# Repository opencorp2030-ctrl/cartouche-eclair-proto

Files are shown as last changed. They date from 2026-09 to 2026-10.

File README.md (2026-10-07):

# CARTOUCHE Drive



A small USB-C drive for an M.2 2230 NVMe SSD, built around the JMicron JMS583
bridge (USB 3.2 Gen 2, 10 Gb/s → PCIe Gen 3 ×2). It is the prototype drive for
[CARTOUCHE](https://cartouche.candygate.eu), a local AI that runs from a USB drive.

**Status:** schematic v0.1 (ERC 0). PCB v0.4 — 36 × 46 mm, 4 layers (In1 GND, In2 GND + 1.0 V island), 9 high-speed pairs as straight coupled pairs. Impedance from a 2D field solver (`tools/impedance.py`, JLC04161H-7628, with solder mask): USB 3.2 pairs 0.20/0.10 mm ≈ 86 Ω (target 90 Ω ±10 %), PCIe and REFCLK pairs 0.30/0.20 mm ≈ 89 Ω (target 85 Ω ±15 %), GND stitching. DRC: 0 unconnected, 0 schematic mismatch, 2 silkscreen warnings. Fabrication files in `hardware/fab/` (Gerbers zip, JLCPCB BOM and CPL). **Prototype, not verified:** JMS583 must be consigned (0 stock at JLCPCB), CPL rotations to check in the JLCPCB viewer, LED polarity assumed active-low.

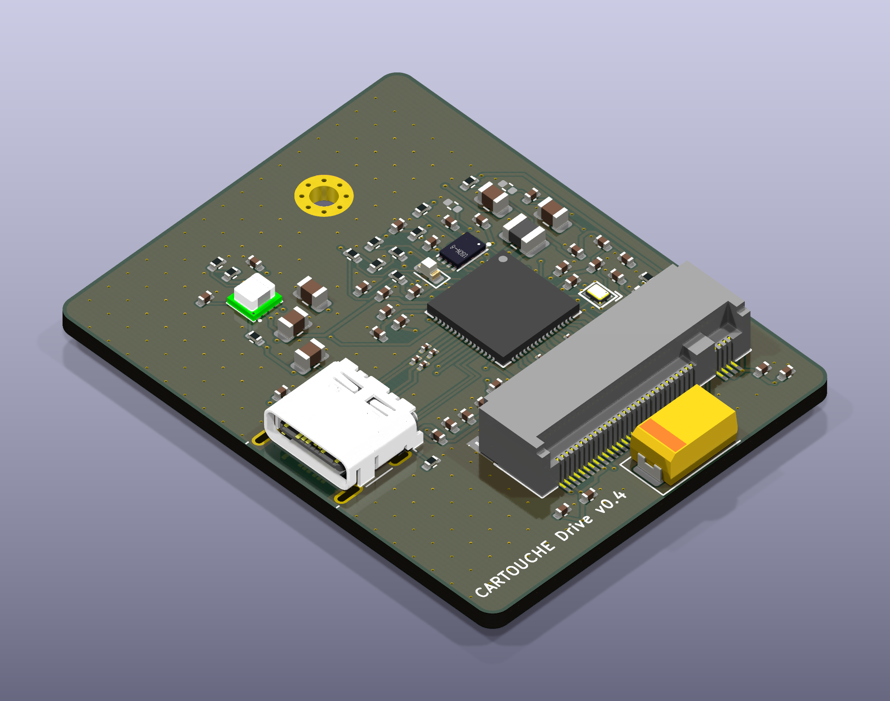
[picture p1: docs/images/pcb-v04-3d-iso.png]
PCB v0.4, 3D view


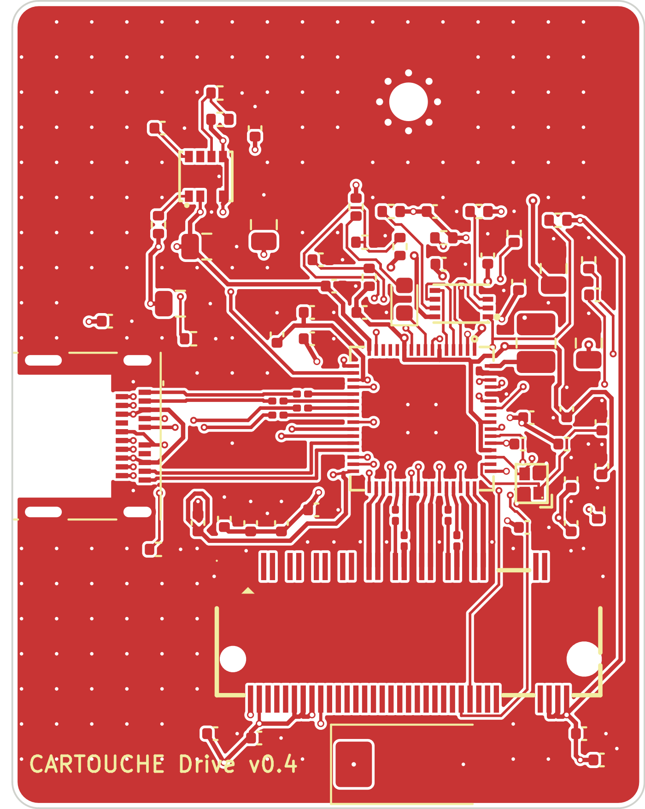
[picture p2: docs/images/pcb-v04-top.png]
top copper
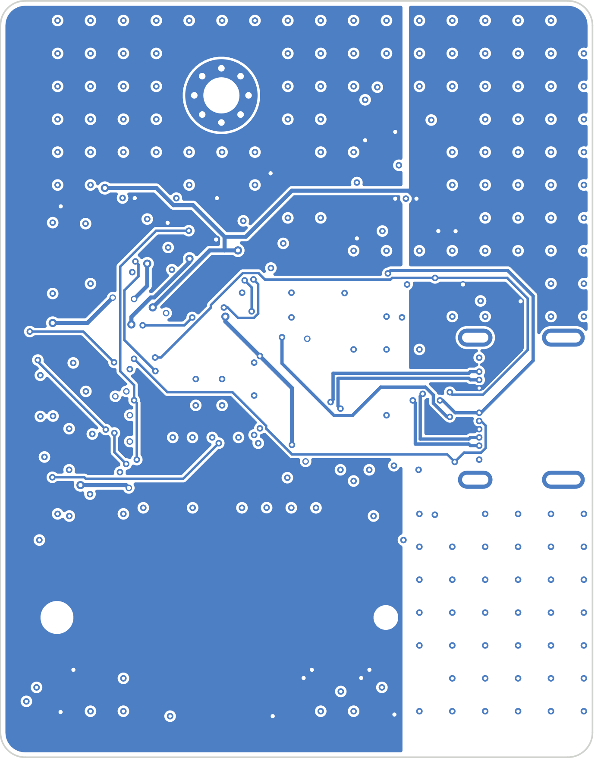
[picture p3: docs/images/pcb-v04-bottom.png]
bottom copper
 

## Blocks

| Block | Parts |
|---|---|
| USB-C (sink, 5 V) | Molex 105450-0101, CC pull-downs 5.1 kΩ, 100 nF on each SuperSpeed TX line |
| Bridge | JMS583 (QFN-64 8×8, 0.4 mm), 25 MHz crystal, REXT 12 kΩ 1 %, reset RC, SPI flash |
| Chip power | JMS583 internal regulators: 5 V → 1.0 V (buck, 4.7 µH) and 5 V → 3.3 V (LDO, chip only) |
| SSD power | TPS82130 3 A buck, 5 V → 3.3 V, 330 µF bulk |
| SSD | LOTES APCI0113 M.2 key M socket, 2 PCIe lanes, 220 nF on each PCIe TX line |

## Files

- `hardware/` — KiCad 9 project (`cartouche-drive.kicad_sch`), local libraries in `hardware/lib/`
- `hardware/cartouche-drive-schematic.pdf` — schematic export
- `tools/gen_schematic.py` — the connection list that generates the schematic
- `tools/build_pcb.py` — board, placement, planes and fan-out vias (KiCad Python)
- `tools/route_pcb.py` — net classes and Freerouting run

## References

- JMS583 datasheet PDS-17001 rev 1.0 (JMicron) — pin-out and required parts
- Part footprints: LCSC / EasyEDA libraries (LOTES C841669, Molex C134092, TPS82130 C473914)

## Sponsors

Thank you to the companies that support this open-source board:

<a href="https://aisler.net">AISLER</a>

- **[AISLER](https://aisler.net) is the PCB sponsor of this project** (boards, stencils and shipping, made in Europe). The AISLER logo is printed on the back of the board (placeholder on `B.Silkscreen`, `tools/aisler_logo.py`). Order your own with the button above.
- **[JMicron](https://www.jmicron.com)**, through its distributor **[BONMECK](https://www.bonmeck.com)**, provides free JMS583 bridge chip samples for the first prototypes.

Results of the prototypes, good or bad, will be published here.

## License

Open source. Hardware (`hardware/`, `docs/`): [CERN-OHL-S-2.0](LICENSE-HARDWARE). Tools (`tools/`): MIT.
See [LICENSE](LICENSE). Third-party libraries used in the KiCad project (KiCad standard libraries, LCSC/EasyEDA
footprints and 3D models) stay under their own licenses.

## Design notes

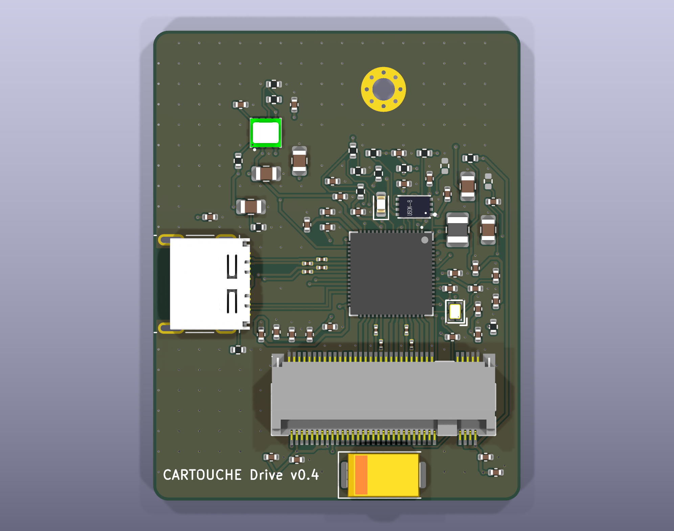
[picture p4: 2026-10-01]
docs/images/pcb-v04-3d-top.png

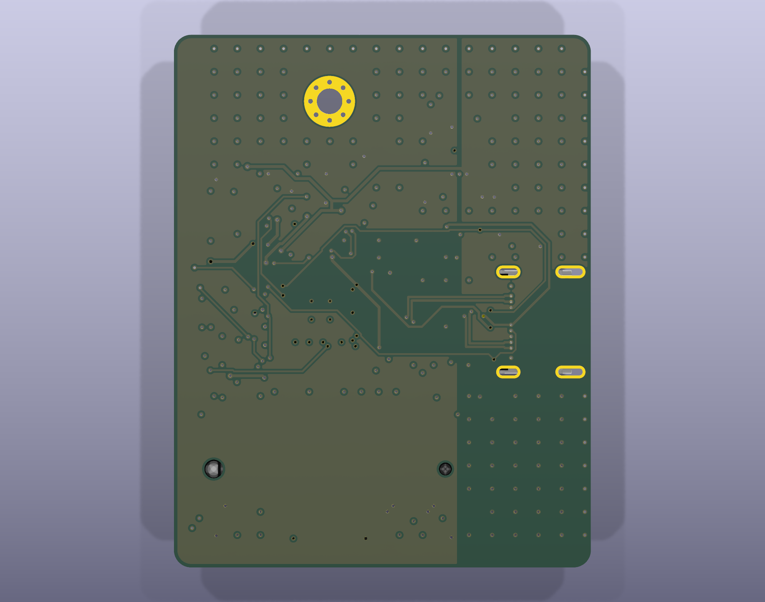
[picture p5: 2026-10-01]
docs/images/pcb-v04-3d-bottom.png

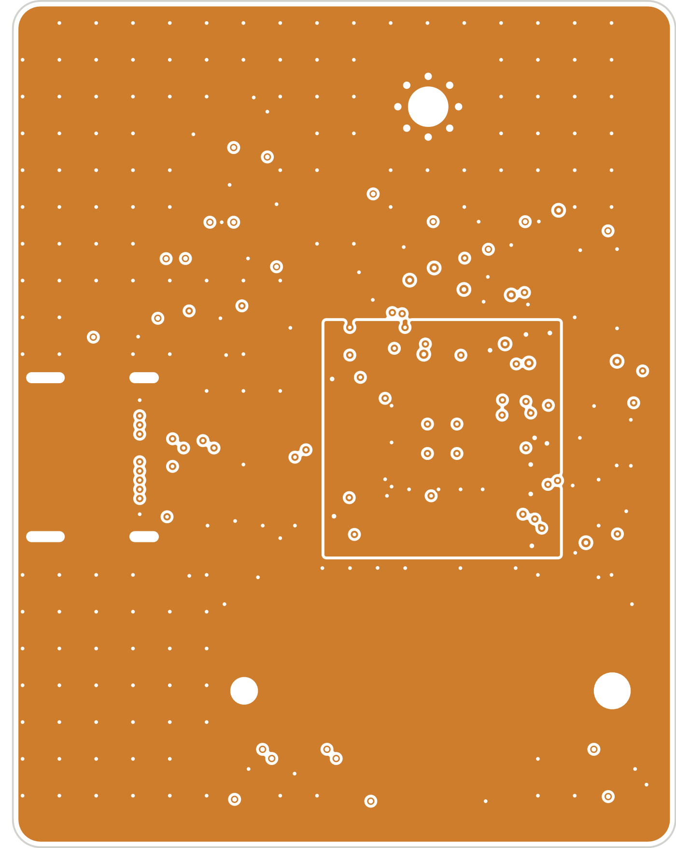
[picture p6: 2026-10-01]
docs/images/pcb-v04-in2.png

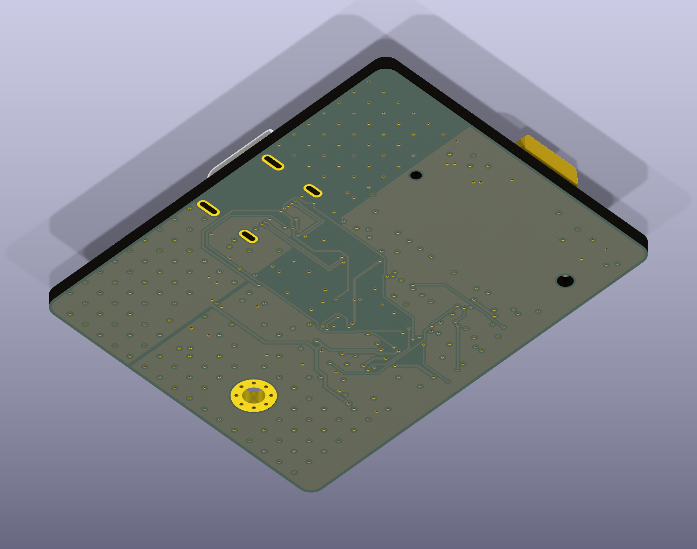
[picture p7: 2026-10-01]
docs/images/pcb-v04-3d-iso-bottom.png

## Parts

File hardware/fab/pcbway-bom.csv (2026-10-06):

Item | Designator | Qty | Manufacturer | Mfg Part # | Description / Value | Package/Footprint | LCSC Part # | Type
1 | C1,C2,C3,C4 | 4 | muRata | GRM033R61A104KE15D | 100nF ±10% 10V Ceramic Capacitor X5R 0201 | 0201 | C76934 | SMD
2 | C5,C28,C38 | 3 | Samsung Electro-Mechanics | CL21A106KAYNNNE | 10uF ±10% 25V Ceramic Capacitor X5R 0805 | 0805 | C15850 | SMD
3 | C6,C9,C10,C11,C12,C13,C14,C15,C16,C17,C18,C19,C20,C23,C24,C25,C26,C27,C29,C33,C42 | 21 | Samsung Electro-Mechanics | CL05B104KO5NNNC | 100nF ±10% 16V Ceramic Capacitor X7R 0402 | 0402 | C1525 | SMD
4 | C7,C40 | 2 | Samsung Electro-Mechanics | CL21A226MAQNNNE | 22uF ±20% 25V Ceramic Capacitor X5R 0805 | 0805 | C45783 | SMD
5 | C8,C22,C43,C44,C45,C46 | 6 | Samsung Electro-Mechanics | CL05A106MQ5NUNC | 10uF ±20% 6.3V Ceramic Capacitor X5R 0402 | 0402 | C15525 | SMD
6 | C21,C30 | 2 | Samsung Electro-Mechanics | CL05A105KA5NQNC | 1uF ±10% 25V Ceramic Capacitor X5R 0402 | 0402 | C52923 | SMD
7 | C31,C32 | 2 | FH | 0402CG180J500NT | 18pF ±5% 50V Ceramic Capacitor C0G 0402 | 0402 | C1549 | SMD
8 | C34,C35,C36,C37 | 4 | muRata | GRM033R60J224ME15D | 220nF ±20% 6.3V Ceramic Capacitor X5R 0201 | 0201 | C76932 | SMD
9 | C39 | 1 | FH | 0402B332K500NT | 3.3nF ±10% 50V Ceramic Capacitor X7R 0402 | 0402 | C1536 | SMD
10 | C41 | 1 | Kyocera AVX | TAJD337M010RNJ | 330uF ±20% 10V Tantalum Capacitors 900mΩ@100kHz CASE-D-7343 | CASE-D-7343-31(mm) | C105408 | SMD
11 | J1 | 1 | MOLEX | 1054500101 | USB-C (USB TYPE-C) Receptacle Connector 24 Position Surface Mount | SMD | C134092 | SMD
12 | J2 | 1 | LOTES | APCI0113-P001A | 67P Surface Mount, Right Angle SMD,P=0.5mm,Surface Mount,Right Angle Centronics Connectors | SMD,P=0.5mm,Surface Mount,Right Angle | C841669 | SMD
13 | L1 | 1 | TDK | MLP2520S4R7ST0S1 | 1A 4.7uH ±20% 110mΩ Multilayer inductor 1008 Fixed Inductors RoHS | 1008 | C383386 | SMD
14 | LED1 | 1 | Hubei KENTO Elec | KT-0603R | Red 645nm LED Indication - Discrete 2.4V 0603 | 0603 | C2286 | SMD
15 | R1,R2 | 2 | UNI-ROYAL | 0402WGF5101TCE | 5.1kΩ ±1% 62.5mW 0402 Thick Film Resistor | 0402 | C25905 | SMD
16 | R3,R6,R10,R11,R12,R13,R14 | 7 | UNI-ROYAL | 0402WGF1002TCE | 10kΩ ±1% 62.5mW 0402 Thick Film Resistor | 0402 | C25744 | SMD
17 | R4 | 1 | UNI-ROYAL | 0402WGF2002TCE | 20kΩ ±1% 62.5mW 0402 Thick Film Resistor | 0402 | C25765 | SMD
18 | R5 | 1 | UNI-ROYAL | 0402WGF1202TCE | 12kΩ ±1% 62.5mW 0402 Thick Film Resistor | 0402 | C25752 | SMD
19 | R9 | 1 | UNI-ROYAL | 0402WGF1001TCE | 1kΩ ±1% 62.5mW 0402 Thick Film Resistor | 0402 | C11702 | SMD
20 | R15 | 1 | FOJAN | FRC0402F4753TS | 475kΩ ±1% 62.5mW 0402 Thick Film Resistor | 0402 | C5713272 | SMD
21 | R16 | 1 | FOJAN | FRC0402F1503TS | 150kΩ ±1% 62.5mW 0402 Thick Film Resistor | 0402 | C2909320 | SMD
22 | U1 | 1 | JMicron | JMS583 | USB 3.2 Gen 2 to PCIe Gen 3 x2 NVMe bridge (needs SPI flash firmware). Please quote sourcing; customer can supply if not available | QFN-64 (8x8 mm) | C9900110183 | SMD
23 | U2 | 1 | TI | TPS82130SILR | Step-down type 900mV~6V 3V~17V USIP-8 DC DC Converters RoHS | USIP-8 | C473914 | SMD
24 | U3 | 1 | Zetta | ZD25WQ16CEIGR | 16Mbit 1.65V~3.6V 104MHz SPI USON-8(2x3) Memory RoHS | USON-8(2x3) | C7304007 | SMD
25 | Y1 | 1 | SCTF | SX0B25.000F1210F30 | Crystal 25MHz ±10ppm 12pF 200Ω SMD1612-4P | SMD1612-4P | C7301914 | SMD

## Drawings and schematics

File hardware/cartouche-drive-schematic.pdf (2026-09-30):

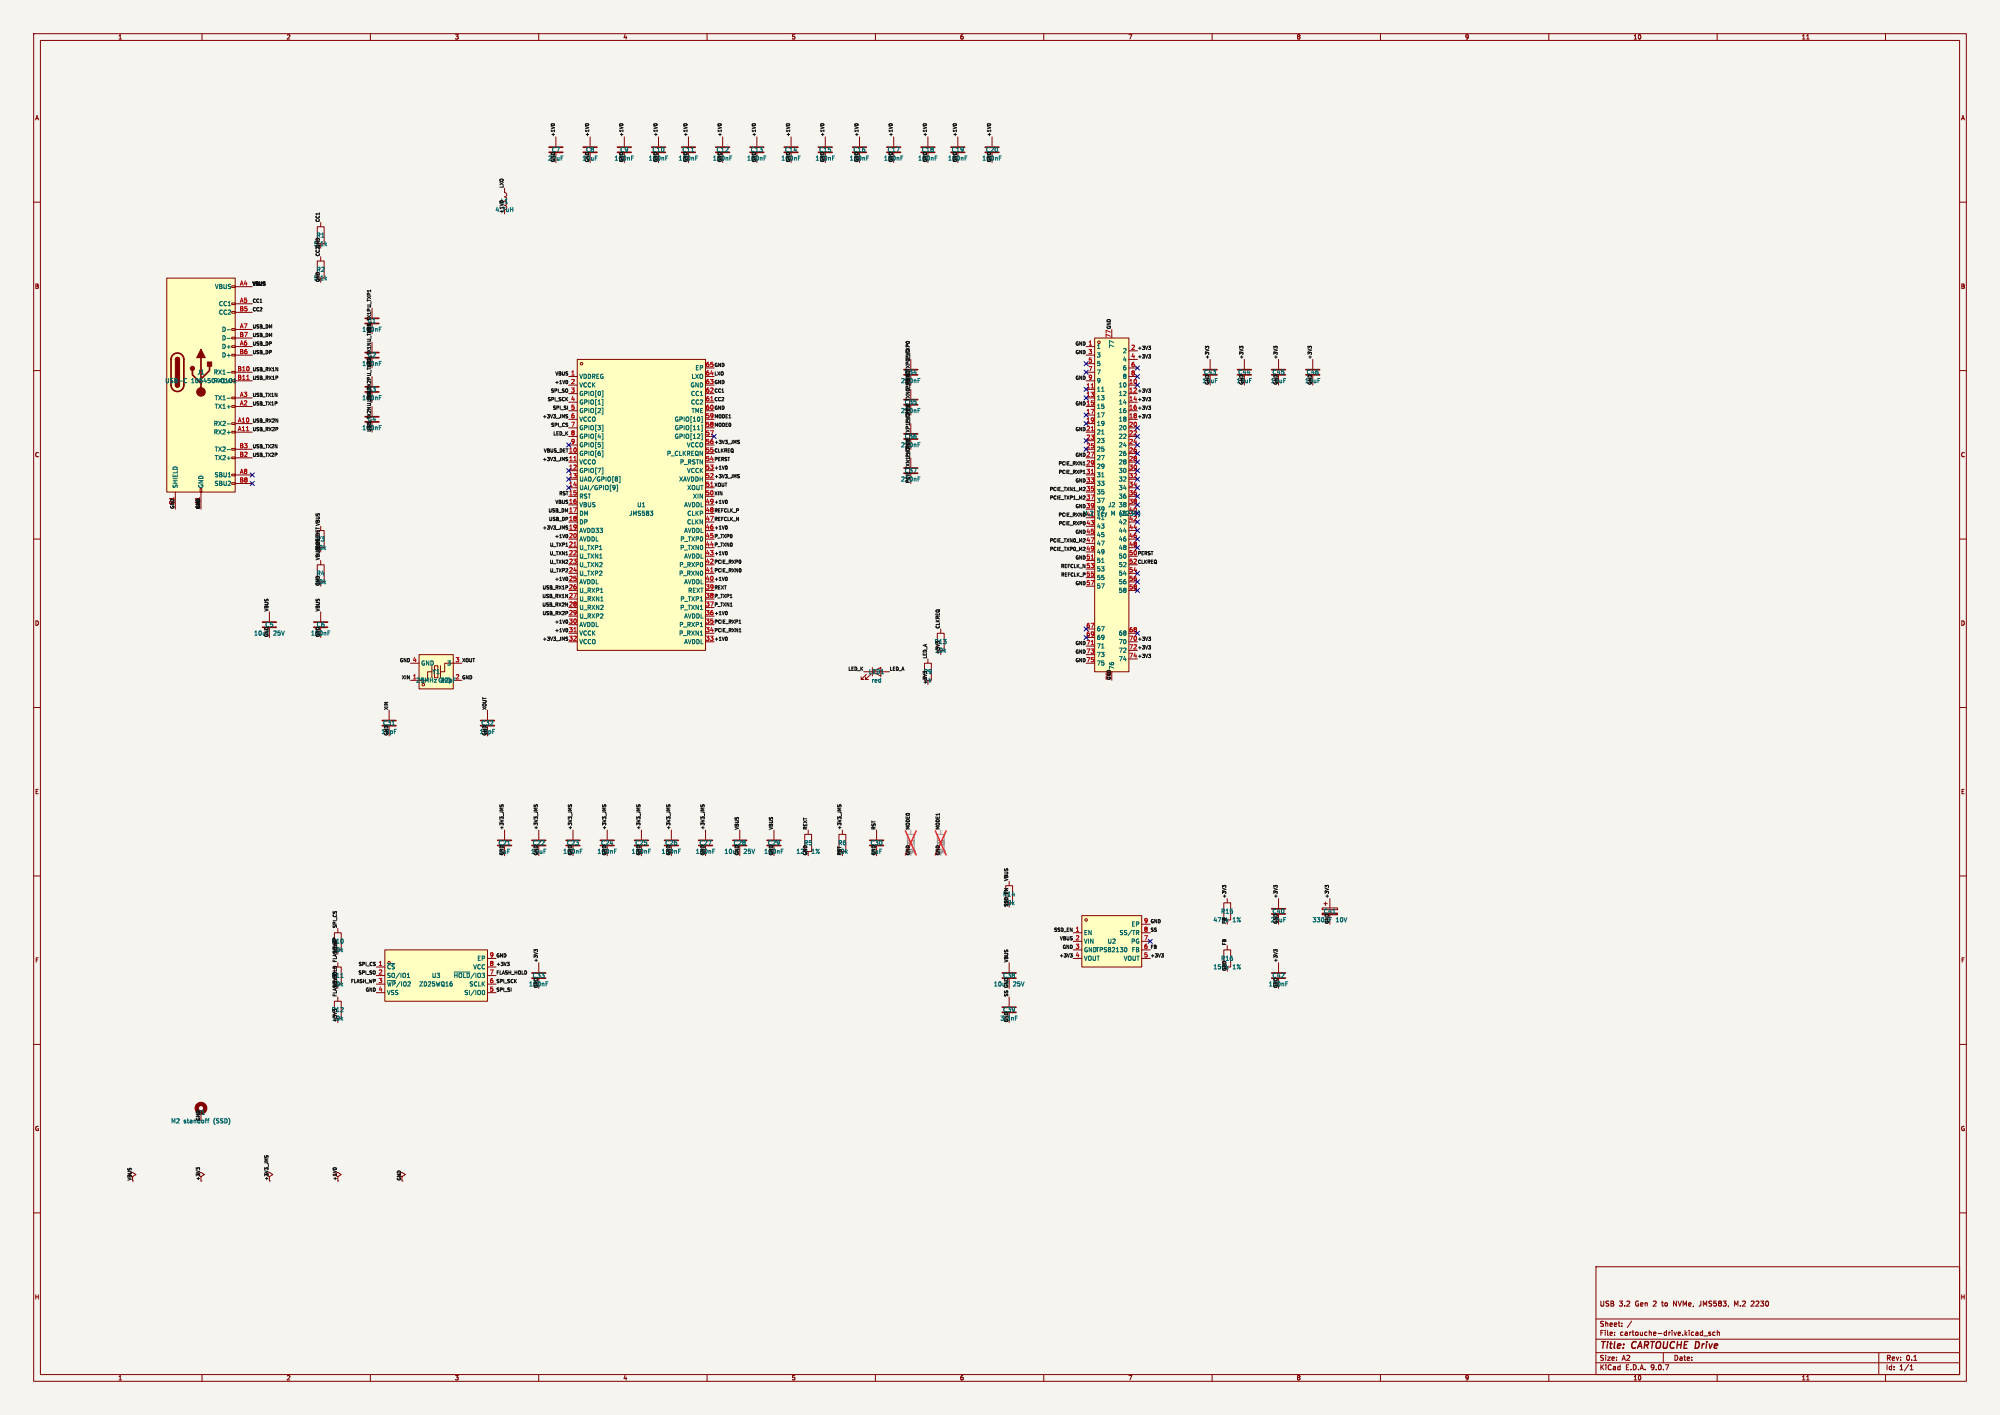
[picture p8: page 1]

LXO 64 GND 63 CC1 62 CC2 61 TME 60 GPIO[10] 59 GPIO[11] 58 GPIO[12] 57 VCCO 56 P_CLKREQN 55 P_RSTN 54 VCCK 53 XAVDDH 52 XOUT 51 XIN 50 AVDDL 49 CLKP 48 CLKN 47 AVDDL 46 P_TXP0 45 P_TXN0 44 AVDDL 43 P_RXP0 42 P_RXN0 41 AVDDL 40 REXT 39 P_TXP1 38 P_TXN1 37 AVDDL 36 P_RXP1 35 P_RXN1 34 AVDDL 33 U1

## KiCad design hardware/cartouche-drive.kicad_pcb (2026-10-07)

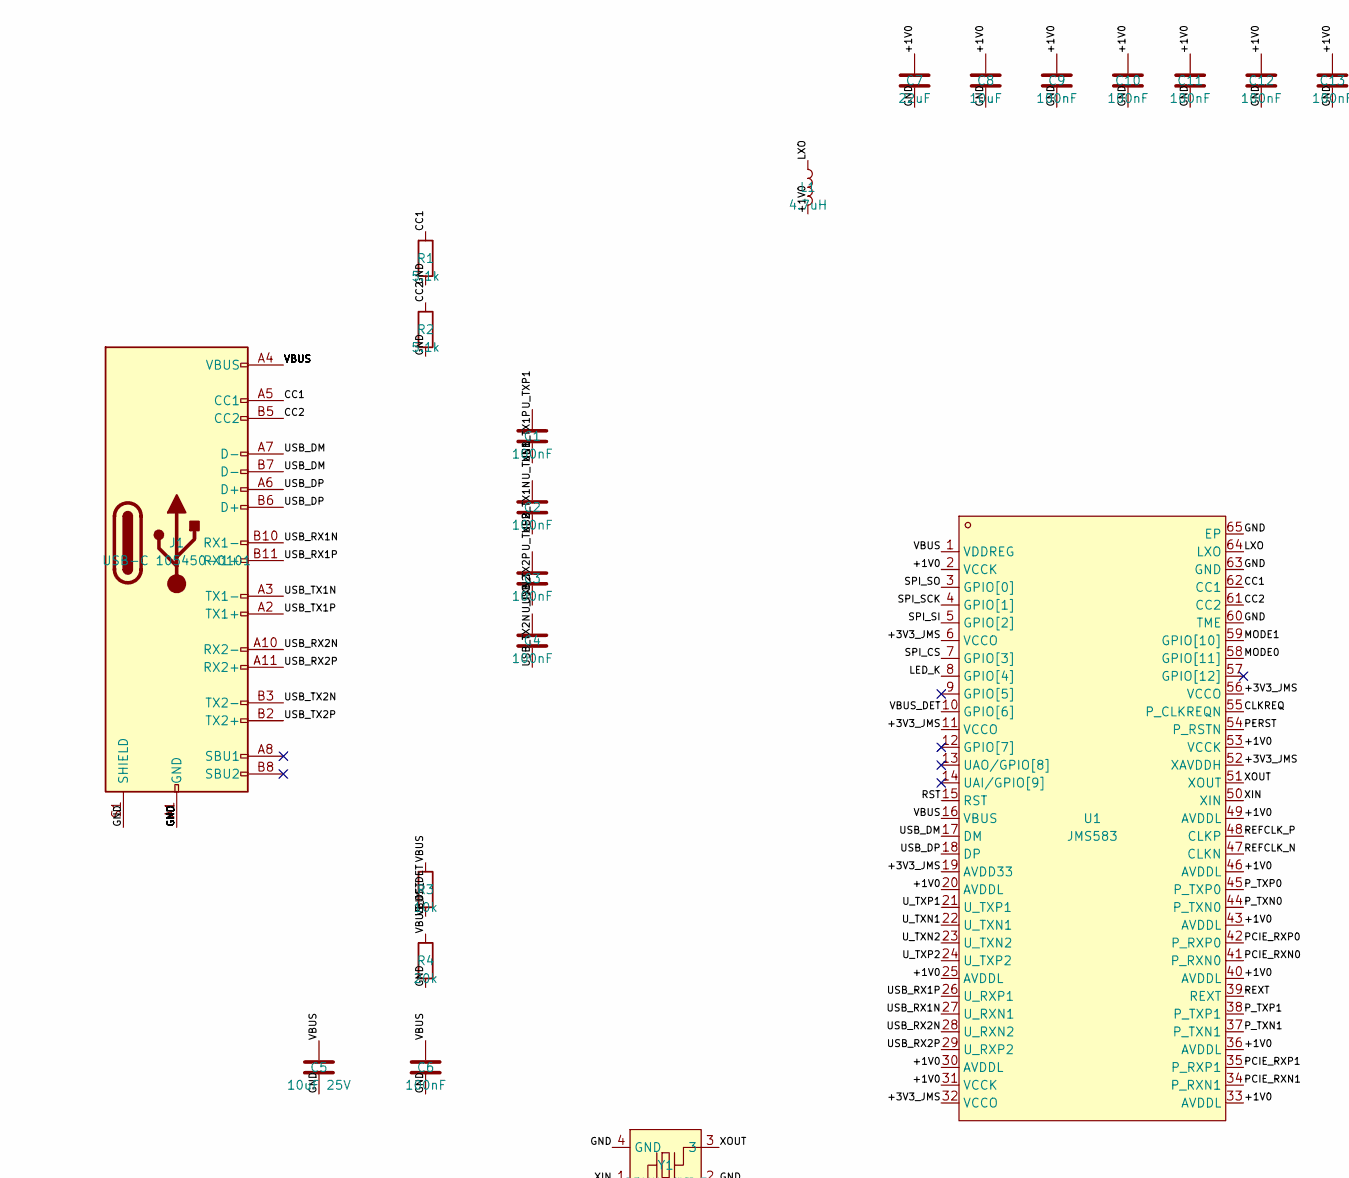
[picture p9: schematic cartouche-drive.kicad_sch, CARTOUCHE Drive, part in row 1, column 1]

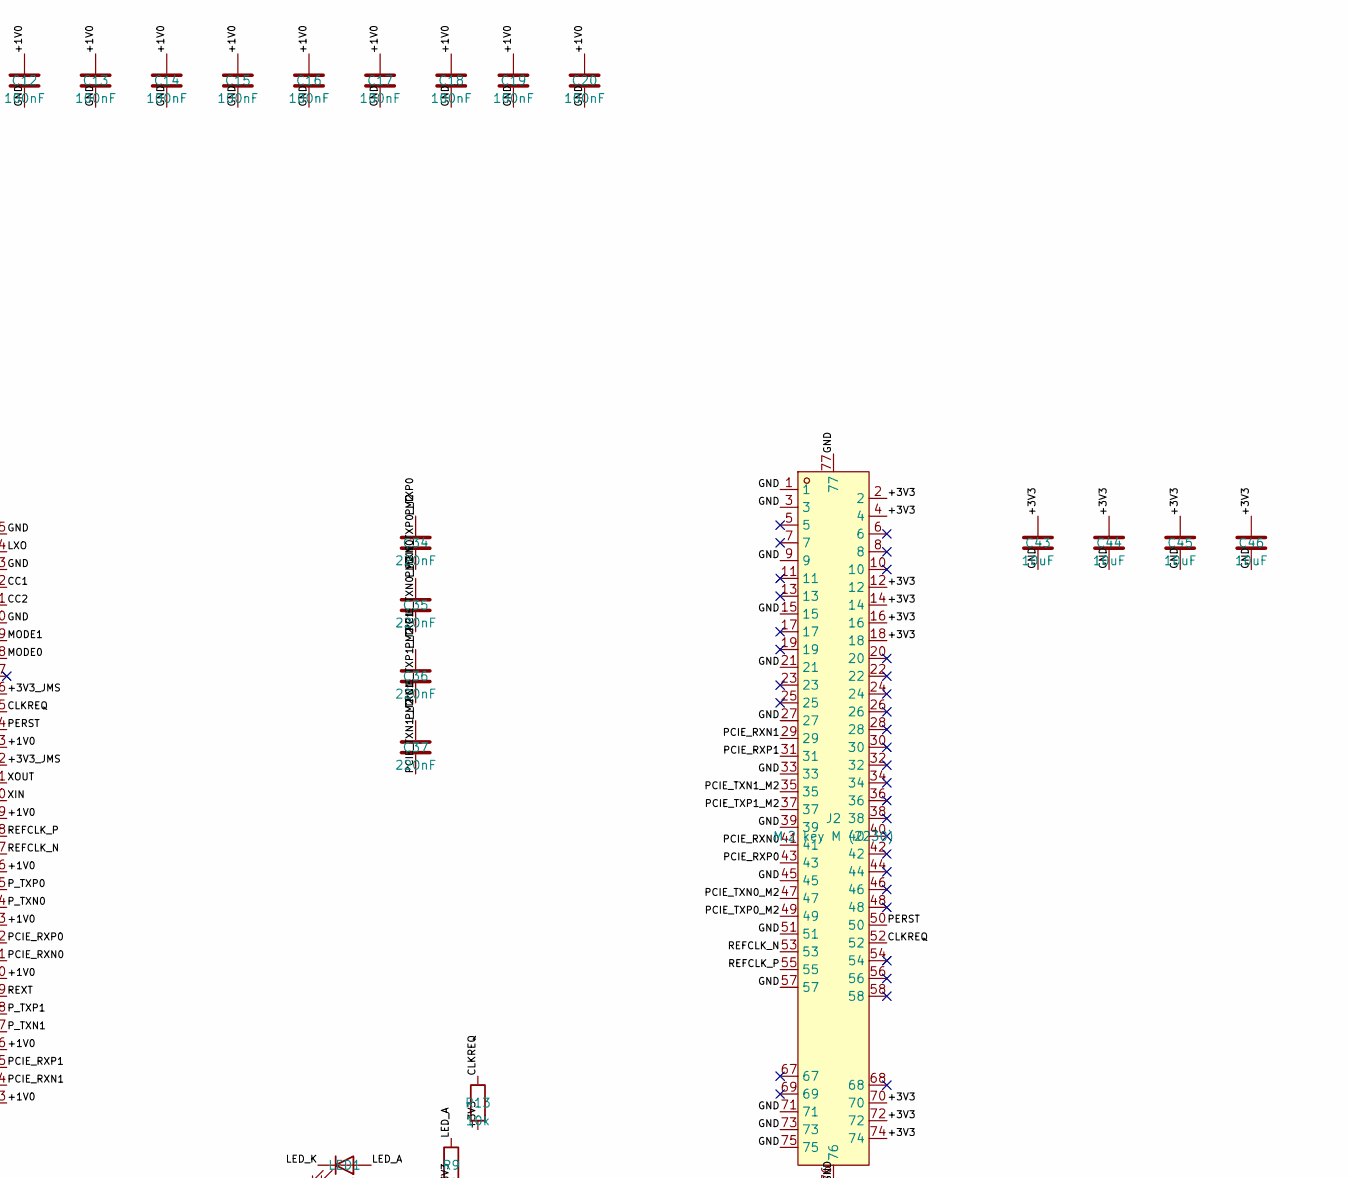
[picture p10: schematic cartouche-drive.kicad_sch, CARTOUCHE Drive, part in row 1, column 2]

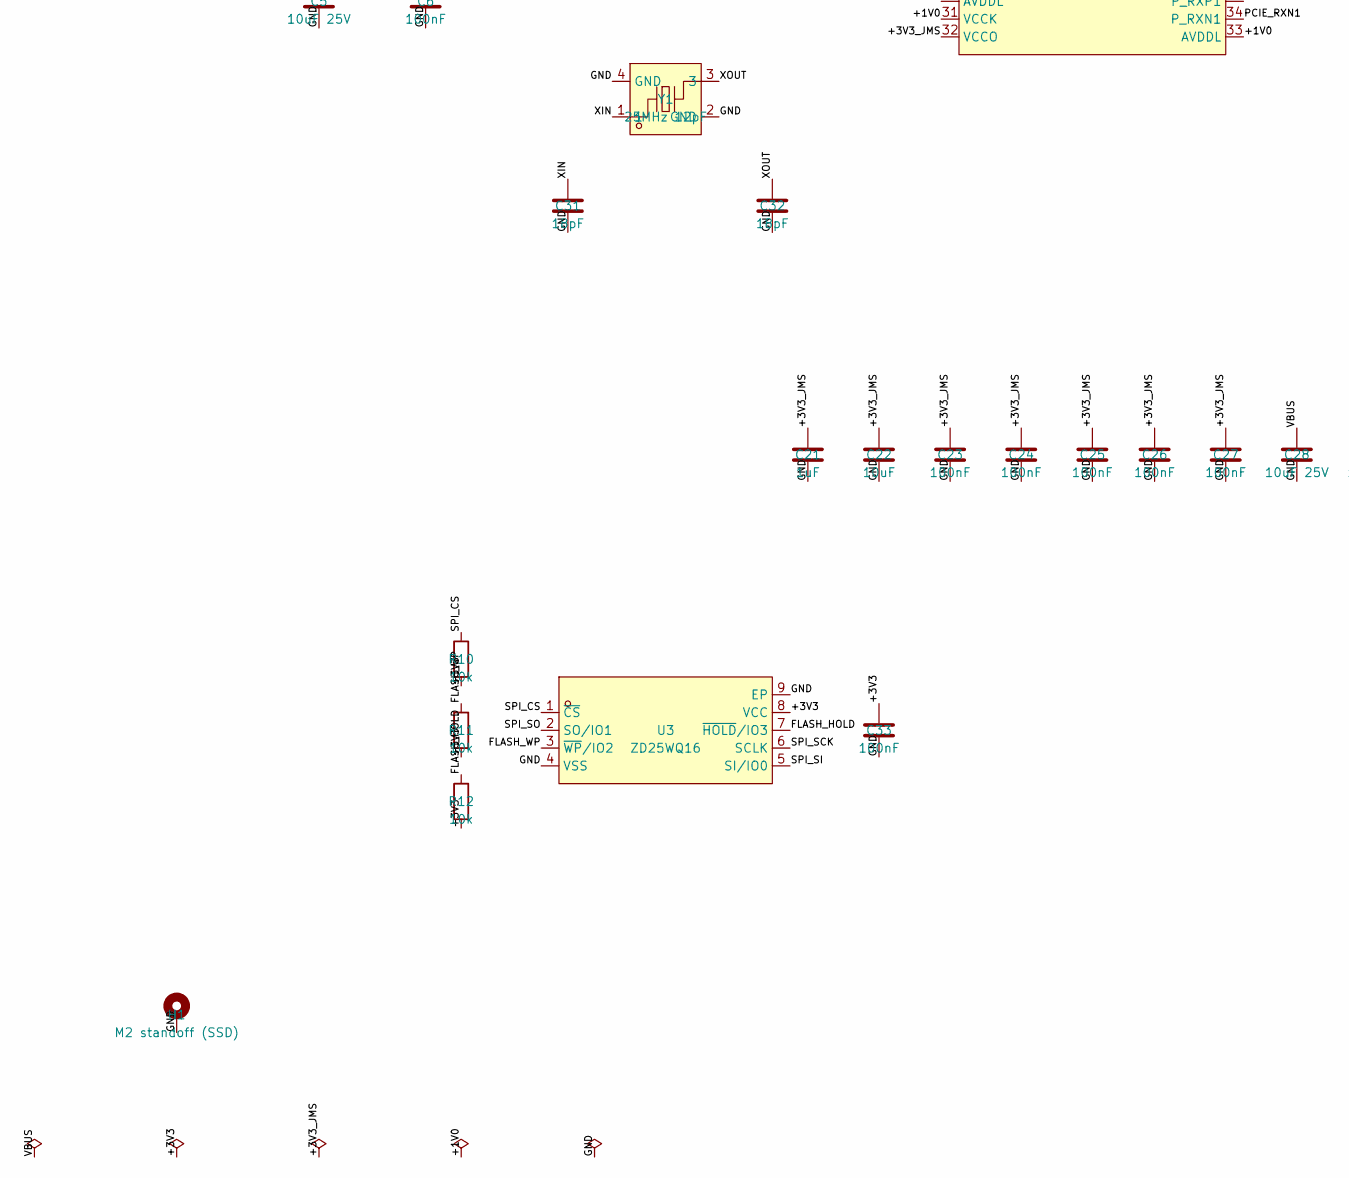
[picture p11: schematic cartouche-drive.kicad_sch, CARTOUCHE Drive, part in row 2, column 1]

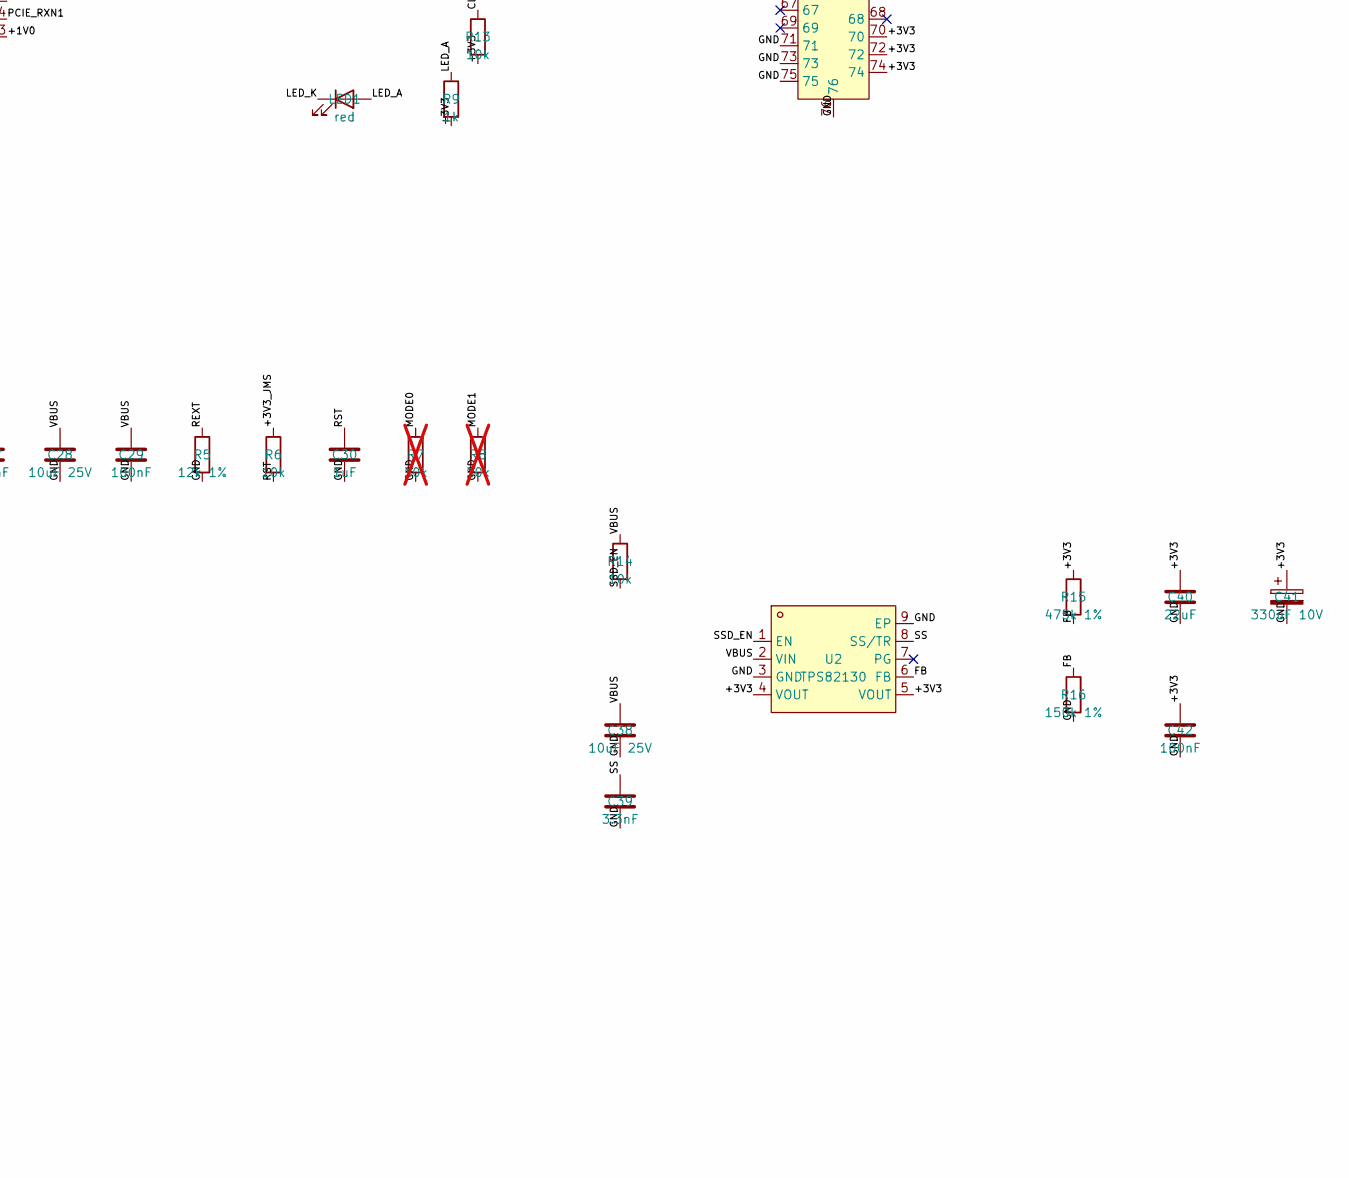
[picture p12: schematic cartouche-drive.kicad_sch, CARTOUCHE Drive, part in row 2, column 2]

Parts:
C1, C2, C3, C4: 100nF; C_0201_0603Metric; LCSC C76934
C5, C28, C38: 10uF 25V; C_0805_2012Metric; LCSC C15850
C6, C9, C10, C11, C12, C13, C14, C15, C16, C17, C18, C19, C20, C23, C24, C25, C26, C27, C29, C33, C42: 100nF; C_0402_1005Metric; LCSC C1525
C7, C40: 22uF; C_0805_2012Metric; LCSC C45783
C8, C22, C43, C44, C45, C46: 10uF; C_0402_1005Metric; LCSC C15525
C21, C30: 1uF; C_0402_1005Metric; LCSC C52923
C31, C32: 18pF; C_0402_1005Metric; LCSC C1549
C34, C35, C36, C37: 220nF; C_0201_0603Metric; LCSC C76932
C39: 3.3nF; C_0402_1005Metric; LCSC C1536
C41: 330uF 10V; CP_EIA-7343-31_Kemet-D; LCSC C105408
H1: M2 standoff (SSD); MountingHole_2.2mm_M2_Pad_Via
J1: USB-C 105450-0101; USB_C_Receptacle_Molex_105450-0101; LCSC C134092
J2: M.2 key M (2230); CONN-SMD_APCI0113-P001A; LCSC C841669
L1: 4.7uH; L_1008_2520Metric; LCSC C383386
LED1: red; LED_0603_1608Metric; LCSC C2286
R1, R2: 5.1k; R_0402_1005Metric; LCSC C25905
R3, R6, R10, R11, R12, R13, R14: 10k; R_0402_1005Metric; LCSC C25744
R4: 20k; R_0402_1005Metric; LCSC C25765
R5: 12k 1%; R_0402_1005Metric; LCSC C25752
R7, R8: 10k; R_0402_1005Metric; LCSC C25744; not fitted
R9: 1k; R_0402_1005Metric; LCSC C11702
R15: 475k 1%; R_0402_1005Metric; LCSC C5713272
R16: 150k 1%; R_0402_1005Metric; LCSC C2909320
U1: JMS583; QFN-64_L8.0-W8.0-P0.40-TL-EP4.5; LCSC C9900110183
U2: TPS82130; USIP-8_L3.0-W2.8-P0.65-TL-EP; LCSC C473914
U3: ZD25WQ16; USON-8_L3.0-W2.0-P0.50-BL-EP; LCSC C7304007
Y1: 25MHz 12pF; CRYSTAL-SMD_4P-L1.6-W1.2-BL; LCSC C7301914

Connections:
/+1V0: C7.1, C8.1, C9.1, C10.1, C11.1, C12.1, C13.1, C14.1, C15.1, C16.1, C17.1, C18.1, C19.1, C20.1, L1.2, U1.2 (VCCK), U1.20 (AVDDL), U1.25 (AVDDL), U1.30 (AVDDL), U1.31 (VCCK), U1.33 (AVDDL), U1.36 (AVDDL), U1.40 (AVDDL), U1.43 (AVDDL), U1.46 (AVDDL), U1.49 (AVDDL), U1.53 (VCCK)
/+3V3: C33.1, C40.1, C41.1, C42.1, C43.1, C44.1, C45.1, C46.1, J2.2, J2.4, J2.12, J2.14, J2.16, J2.18, J2.70, J2.72, J2.74, R9.2, R10.2, R11.2, R12.2, R13.2, R15.1, U2.4 (VOUT), U2.5 (VOUT), U3.8 (VCC)
/+3V3_JMS: C21.1, C22.1, C23.1, C24.1, C25.1, C26.1, C27.1, R6.1, U1.6 (VCCO), U1.11 (VCCO), U1.19 (AVDD33), U1.32 (VCCO), U1.52 (XAVDDH), U1.56 (VCCO)
/CC1: J1.A5 (CC1), R1.1, U1.62 (CC1)
/CC2: J1.B5 (CC2), R2.1, U1.61 (CC2)
/CLKREQ: J2.52, R13.1, U1.55 (P_CLKREQN)
/FB: R15.2, R16.1, U2.6 (FB)
/FLASH_HOLD: R12.1, U3.7 (~HOLD/IO3)
/FLASH_WP: R11.1, U3.3 (~WP/IO2)
/GND: C5.2, C6.2, C7.2, C8.2, C9.2, C10.2, C11.2, C12.2, C13.2, C14.2, C15.2, C16.2, C17.2, C18.2, C19.2, C20.2, C21.2, C22.2, C23.2, C24.2, C25.2, C26.2, C27.2, C28.2, C29.2, C30.2, C31.2, C32.2, C33.2, C38.2, C39.2, C40.2, C41.2, C42.2, C43.2, C44.2, C45.2, C46.2, H1.1, J1.A1 (GND), J1.A12 (GND), J1.B1 (GND), J1.B12 (GND), J1.S1 (SHIELD), J2.1, J2.3, J2.9, J2.15, J2.21, J2.27, J2.33, J2.39, J2.45, J2.51, J2.57, J2.71, J2.73, J2.75, J2.76, J2.77, R1.2, R2.2, R4.2, R5.2, R7.2, R8.2, R16.2, U1.60 (TME), U1.63 (GND), U1.65 (EP), U2.3 (GND), U2.9 (EP), U3.4 (VSS), U3.9 (EP), Y1.2 (GND), Y1.4 (GND)
/LED_A: LED1.2 (A), R9.1
/LED_K: LED1.1 (K), U1.8 (GPIO[4])
/LXO: L1.1, U1.64 (LXO)
/MODE0: R7.1, U1.58 (GPIO[11])
/MODE1: R8.1, U1.59 (GPIO[10])
/PCIE_RXN0: J2.41, U1.41 (P_RXN0)
/PCIE_RXN1: J2.29, U1.34 (P_RXN1)
/PCIE_RXP0: J2.43, U1.42 (P_RXP0)
/PCIE_RXP1: J2.31, U1.35 (P_RXP1)
/PCIE_TXN0_M2: C35.2, J2.47
/PCIE_TXN1_M2: C37.2, J2.35
/PCIE_TXP0_M2: C34.2, J2.49
/PCIE_TXP1_M2: C36.2, J2.37
/PERST: J2.50, U1.54 (P_RSTN)
/P_TXN0: C35.1, U1.44 (P_TXN0)
/P_TXN1: C37.1, U1.37 (P_TXN1)
/P_TXP0: C34.1, U1.45 (P_TXP0)
/P_TXP1: C36.1, U1.38 (P_TXP1)
/REFCLK_N: J2.53, U1.47 (CLKN)
/REFCLK_P: J2.55, U1.48 (CLKP)
/REXT: R5.1, U1.39 (REXT)
/RST: C30.1, R6.2, U1.15 (RST)
/SPI_CS: R10.1, U1.7 (GPIO[3]), U3.1 (~CS)
/SPI_SCK: U1.4 (GPIO[1]), U3.6 (SCLK)
/SPI_SI: U1.5 (GPIO[2]), U3.5 (SI/IO0)
/SPI_SO: U1.3 (GPIO[0]), U3.2 (SO/IO1)
/SS: C39.1, U2.8 (SS/TR)
/SSD_EN: R14.2, U2.1 (EN)
/USB_DM: J1.A7 (D-), J1.B7 (D-), U1.17 (DM)
/USB_DP: J1.A6 (D+), J1.B6 (D+), U1.18 (DP)
/USB_RX1N: J1.B10 (RX1-), U1.27 (U_RXN1)
/USB_RX1P: J1.B11 (RX1+), U1.26 (U_RXP1)
/USB_RX2N: J1.A10 (RX2-), U1.28 (U_RXN2)
/USB_RX2P: J1.A11 (RX2+), U1.29 (U_RXP2)
/USB_TX1N: C2.2, J1.A3 (TX1-)
/USB_TX1P: C1.2, J1.A2 (TX1+)
/USB_TX2N: C4.2, J1.B3 (TX2-)
/USB_TX2P: C3.2, J1.B2 (TX2+)
/U_TXN1: C2.1, U1.22 (U_TXN1)
/U_TXN2: C4.1, U1.23 (U_TXN2)
/U_TXP1: C1.1, U1.21 (U_TXP1)
/U_TXP2: C3.1, U1.24 (U_TXP2)
/VBUS: C5.1, C6.1, C28.1, C29.1, C38.1, J1.A4 (VBUS), J1.A9 (VBUS), J1.B4 (VBUS), J1.B9 (VBUS), R3.1, R14.1, U1.1 (VDDREG), U1.16 (VBUS), U2.2 (VIN)
/VBUS_DET: R3.2, R4.1, U1.10 (GPIO[6])
/XIN: C31.1, U1.50 (XIN), Y1.1
/XOUT: C32.1, U1.51 (XOUT), Y1.3

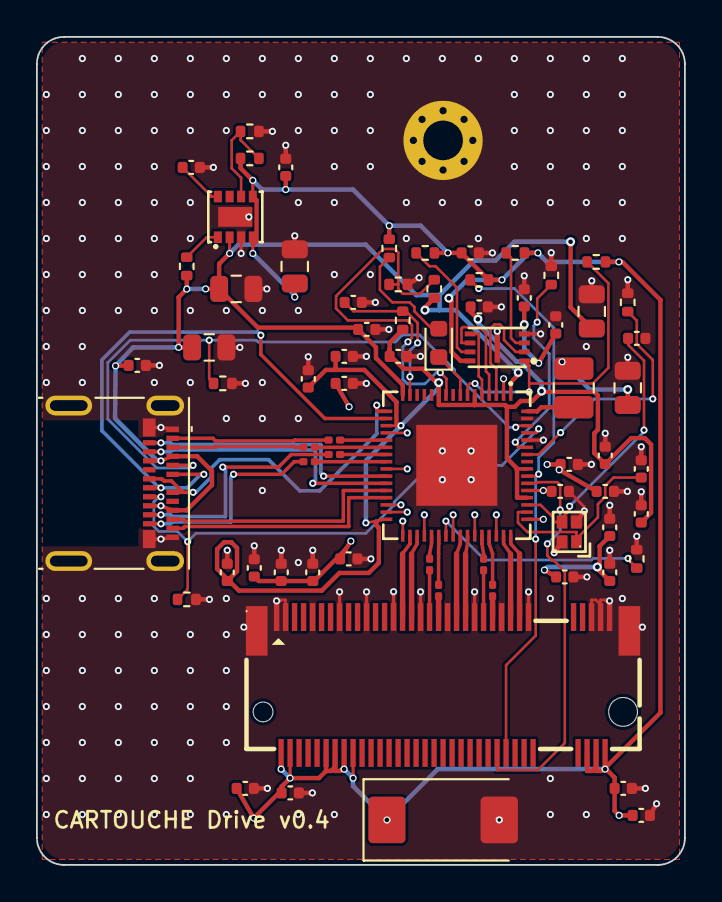
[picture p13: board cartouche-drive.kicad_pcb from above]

Board: 4 copper layers, 36.0 x 46.0 mm, 71 parts (0 on the bottom side), 56 nets.

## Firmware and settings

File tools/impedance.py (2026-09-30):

"""2D field solver for the board's outer-layer lines (finite differences, Laplace).

  python3 tools/impedance.py        (needs numpy and scipy)

Stack-up JLC04161H-7628 (JLCPCB 4 layers, 1.6 mm): L1 copper 0.035 mm over 0.2104 mm
of 7628 prepreg (er 4.4) above the L2 ground plane. Solder mask 0.015 mm, er 3.8.
Prints single-ended and differential (edge-coupled) impedances; the differential one
is twice the odd-mode impedance, computed as 1 / (c * sqrt(C * C_air)).
"""
import numpy as np
import scipy.sparse as sp
import scipy.sparse.linalg as spl

D = 0.005                        # grid step, mm
H, T, ER = 0.2104, 0.035, 4.4    # prepreg, copper, prepreg permittivity
TM, ERM = 0.015, 3.8             # solder mask
C0 = 299792458.0
E0 = 8.8541878128e-12


def solve(w, s=None, mask=True, air=False):
    nx, ny = int(round(4.0 / D)), int(round(1.5 / D))
    jh, jt = int(round(H / D)), int(round((H + T) / D))
    xc = nx // 2
    wi = int(round(w / D))
    if s is None:
        spans = [(xc - wi // 2, xc - wi // 2 + wi, 1.0)]
    else:
        si = int(round(s / D))
        a = xc - si // 2
        spans = [(a - wi, a, 1.0), (a + si, a + si + wi, -1.0)]
    # cell permittivity (cells between nodes), rows 0..ny-1, cols 0..nx-1
    eps = np.ones((ny, nx))
    if not air:
        eps[:jh, :] = ER
        if mask:
            m = int(round(TM / D))
            eps[jh:jh + m, :] = ERM
            for x0, x1, _ in spans:
                eps[jh:jt + m, max(x0 - m, 0):x1 + m] = ERM
    # node potentials fixed: plane row 0 and outer box = 0, traces = ±1
    fixed = np.zeros((ny + 1, nx + 1), bool)
    val = np.zeros((ny + 1, nx + 1))
    fixed[0, :] = fixed[-1, :] = True
    fixed[:, 0] = fixed[:, -1] = True
    for x0, x1, v in spans:
        fixed[jh:jt + 1, x0:x1 + 1] = True
        val[jh:jt + 1, x0:x1 + 1] = v
    idx = -np.ones(fixed.shape, int)
    free = np.argwhere(~fixed)
    idx[~fixed] = np.arange(len(free))

    def edge(j, i, dj, di):          # permittivity of the edge from node (j,i) to its neighbour
        if dj:                        # vertical edge inside cell row min(j, j+dj)
            r = min(j, j + dj)
            return 0.5 * (eps[r, max(i - 1, 0)] + eps[r, min(i, nx - 1)])
        c = min(i, i + di)
        return 0.5 * (eps[max(j - 1, 0), c] + eps[min(j, ny - 1), c])

    rows, cols, data = [], [], []
    b = np.zeros(len(free))
    for k, (j, i) in enumerate(free):
        diag = 0.0
        for dj, di in ((1, 0), (-1, 0), (0, 1), (0, -1)):
            e = edge(j, i, dj, di)
            diag += e
            jj, ii = j + dj, i + di
            if fixed[jj, ii]:
                b[k] += e * val[jj, ii]
            else:
                rows.append(k); cols.append(idx[jj, ii]); data.append(-e)
        rows.append(k); cols.append(k); data.append(diag)
    A = sp.csr_matrix((data, (rows, cols)), shape=(len(free), len(free)))
    V = val.copy()
    V[~fixed] = spl.spsolve(A, b)
    # charge on the +1 conductor: flux through the edges leaving it
    x0, x1, _ = spans[0]
    q = 0.0
    for j in range(jh, jt + 1):
        for i in range(x0, x1 + 1):
            for dj, di in ((1, 0), (-1, 0), (0, 1), (0, -1)):
                jj, ii = j + dj, i + di
                if not (jh <= jj <= jt and x0 <= ii <= x1):
                    q += edge(j, i, dj, di) * (1.0 - V[jj, ii])
    return q * E0                    # F/m (grid step cancels in 2D)


def z(w, s=None, mask=True):
    c, ca = solve(w, s, mask), solve(w, s, mask, air=True)
    zz = 1.0 / (C0 * np.sqrt(c * ca))
    return zz * 2 if s is not None else zz, c / ca


if __name__ == "__main__":
    print("single-ended (check, 50 ohm expected near w 0.35 mm):")
    for w in (0.30, 0.35, 0.40):
        print(f"  w {w:.2f}: {z(w)[0]:5.1f} ohm (mask), {z(w, mask=False)[0]:5.1f} ohm (no mask)")
    print("differential, edge-coupled on L1 over L2:")
    for w, s in ((0.20, 0.10), (0.18, 0.10), (0.16, 0.10), (0.20, 0.15), (0.18, 0.15), (0.20, 0.20)):
        print(f"  w {w:.2f} gap {s:.2f}: {z(w, s)[0]:5.1f} ohm (mask), {z(w, s, mask=False)[0]:5.1f} ohm (no mask)")

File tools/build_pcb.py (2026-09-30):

"""Builds hardware/cartouche-drive.kicad_pcb from the schematic netlist (KiCad 9 Python).

Run with KiCad's own Python (it has pcbnew):
  "C:\\Program Files\\KiCad\\9.0\\bin\\python.exe" tools\\build_pcb.py
Steps: read the netlist, load every footprint, place it, assign the nets,
draw the outline, set the 4-layer stack and design rules, add the ground
planes, then export a Specctra DSN for Freerouting.

Board frame (mm, KiCad y goes down): 36 x 46 mm. The M.2 2230 SSD lies over the
right part of the board (on its 4.75 mm connector and an M2 standoff). The JMS583
sits under the SSD with its PCIe side facing the socket's PCIe pins (same order,
no crossing); the USB-C receptacle is on the left edge, facing the USB side.
"""
import os
import re
import sys
import pcbnew

HERE = os.path.dirname(os.path.abspath(__file__))
HW = os.path.join(os.path.dirname(HERE), "hardware")
KFP = r"C:\Program Files\KiCad\9.0\share\kicad\footprints"
NET = os.path.join(HW, "cartouche-drive.net")
OUT = os.path.join(HW, "cartouche-drive.kicad_pcb")
W, H = 36.0, 46.0

mm = pcbnew.FromMM


def P(x, y):
    return pcbnew.VECTOR2I(mm(x), mm(y))


# ---------------------------------------------------------------- netlist
txt = open(NET, encoding="utf8").read()
comps = {}
for m in re.finditer(r'\(comp \(ref "([^"]+)"\)(.*?)\(sheetpath', txt, re.S):
    body = m.group(2)
    fp = re.search(r'\(footprint "([^"]*)"\)', body)
    val = re.search(r'\(value "([^"]*)"\)', body)
    comps[m.group(1)] = dict(fp=fp.group(1) if fp else "", value=val.group(1) if val else "")
nets = {}
for m in re.finditer(r'\(net \(code "\d+"\) \(name "([^"]+)"\)(.*?)(?=\(net \(code|\)\s*\)\s*$)', txt, re.S):
    for r, p in re.findall(r'\(ref "([^"]+)"\) \(pin "([^"]+)"', m.group(2)):
        nets[(r, p)] = m.group(1)

# ---------------------------------------------------------------- placement (x, y, rotation)
# Big parts are placed by hand; every small part is then placed automatically
# as close as possible to the pad it serves (same net on a big part), without
# overlapping anything (courtyards + 0.25 mm), on a 0.25 mm grid.
JX = 23.24                       # socket centre: puts the socket's PCIe pins right under the chip's
PLACE = {
    "J2": (JX, 36.0, 0),         # M.2 socket; card edge at y 35.75, SSD up to y 5.75
    "H1": (JX, 5.75, 0),         # M2 standoff at the far end of a 2230 card
    "U1": (24.0, 23.8, 270),     # JMS583, PCIe side down (towards J2), USB side left (towards J1)
    "J1": (5.0, 24.8, 270),      # USB-C, mouth on the left edge
    "U2": (11.7, 10.0, 90),      # SSD 3.3 V buck: VIN on the VBUS side (left), VOUT on the +3V3 side
    "C41": (JX, 43.5, 0),        # 330 uF tantalum (3.1 mm tall): below the socket, outside the SSD
}
BIG = ["J2", "U1", "J1", "U2", "C41", "H1"]
NEAR = {"Y1": ("U1", "50"), "U3": ("U1", "5"), "L1": ("U1", "64"), "LED1": ("U1", "8"),
        # one 100 nF per power pin of the JMS583, as close as possible to that pin
        **{f"C{9+i}": ("U1", p) for i, p in enumerate(["2", "20", "25", "30", "31", "33", "36", "40", "43", "46", "49", "53"])},
        **{f"C{23+i}": ("U1", p) for i, p in enumerate(["6", "11", "32", "56", "52"])},
        "C21": ("U1", "19"), "C22": ("U1", "19"), "C28": ("U1", "1"), "C29": ("U1", "16"), "C7": ("U1", "64"), "C8": ("U1", "64"),
        "R5": ("U1", "39"), "R6": ("U1", "15"), "C30": ("U1", "15"), "R3": ("U1", "10"), "R4": ("U1", "10"),
        "C31": ("U1", "50"), "C32": ("U1", "51"), "R7": ("U1", "58"), "R8": ("U1", "59"),
        "C1": ("U1", "21"), "C2": ("U1", "22"), "C3": ("U1", "24"), "C4": ("U1", "23"),
        "C34": ("U1", "45"), "C35": ("U1", "44"), "C36": ("U1", "38"), "C37": ("U1", "37"), "R13": ("U1", "55"),
        "R1": ("J1", "A5"), "R2": ("J1", "B5"), "C5": ("J1", "A4"), "C6": ("J1", "B9"),
        # SSD buck: around U2
        "R14": ("U2", "1"), "C38": ("U2", "2"), "C39": ("U2", "8"), "R15": ("U2", "6"), "R16": ("U2", "6"),
        "C40": ("U2", "4"), "C42": ("U2", "5"),
        # M.2 3.3 V pins
        "C43": ("J2", "2"), "C44": ("J2", "12"), "C45": ("J2", "70"), "C46": ("J2", "74"),
        "R10": ("U3", "1"), "R11": ("U3", "3"), "R12": ("U3", "7"), "C33": ("U3", "8"), "R9": ("LED1", "2")}
# ---------------------------------------------------------------- board
board = pcbnew.BOARD()
board.SetCopperLayerCount(4)
ds = board.GetDesignSettings()
ds.m_TrackMinWidth = mm(0.09)
ds.m_MinClearance = mm(0.09)
ds.m_ViasMinSize = mm(0.35)
ds.m_MinThroughDrill = mm(0.2)
ds.m_CopperEdgeClearance = mm(0.3)
ds.m_HoleClearance = mm(0.2)
ds.m_HoleToHoleMin = mm(0.2)
ds.m_ViasMinAnnularWidth = mm(0.075)
ds.SetBoardThickness(mm(1.6))
nc = ds.m_NetSettings.GetDefaultNetclass()
nc.SetTrackWidth(mm(0.15))
nc.SetClearance(mm(0.1))
nc.SetViaDiameter(mm(0.4))
nc.SetViaDrill(mm(0.2))

netinfo = {}


def net(name):
    if name not in netinfo:
        n = pcbnew.NETINFO_ITEM(board, name)
        board.Add(n)
        netinfo[name] = n
    return netinfo[name]


for ref, c in sorted(comps.items()):
    if not c["fp"]:
        continue
    lib, name = c["fp"].split(":")
    path = os.path.join(HW, "lib", "cartouche.pretty") if lib == "cartouche" else os.path.join(KFP, lib + ".pretty")
    fp = pcbnew.FootprintLoad(path, name)
    if fp is None:
        sys.exit(f"footprint not found: {c['fp']}")
    fp.SetReference(ref)
    fp.SetValue(c["value"])
    fp.SetFPIDAsString(c["fp"])
    if ref in ("R7", "R8"):
        fp.SetDNP(True)
    if ref.startswith("H"):
        fp.SetExcludedFromBOM(True)
    x, y, rot = PLACE.get(ref, (W / 2, H + 20, 0))
    board.Add(fp)
    fp.SetPosition(P(x, y))
    fp.SetOrientationDegrees(rot)
    for pad in fp.Pads():
        n = nets.get((ref, pad.GetNumber()))
        if n:
            pad.SetNet(net(n))

# ---------------------------------------------------------------- automatic placement of the small parts
fps = {f.GetReference(): f for f in board.GetFootprints()}
SSD = (JX - 11.3, 5.0, JX + 11.3, 36.0)          # SSD shadow: only parts lower than 2.5 mm
TALL = {"C41", "J1"}
occupied = []
placed_done = set()


def box(f, margin=0.25):
    bb = f.GetBoundingBox(False, False)
    return (pcbnew.ToMM(bb.GetLeft()) - margin, pcbnew.ToMM(bb.GetTop()) - margin,
            pcbnew.ToMM(bb.GetRight()) + margin, pcbnew.ToMM(bb.GetBottom()) + margin)


def free(b):
    if b[0] < 0.4 or b[1] < 0.4 or b[2] > W - 0.4 or b[3] > H - 0.4:
        return False
    if b[1] < 8.5 and b[3] > 3.0 and b[0] < JX + 3 and b[2] > JX - 3:   # keep the standoff clear
        return False
    if b[3] > 27.3 and b[1] < 32.4 and b[0] < 28.8 and b[2] > 19.8:      # PCIe channel: kept for the pairs
        return False
    if b[2] > 8.8 and b[0] < 20.0 and b[3] > 20.2 and b[1] < 28.2:       # USB channel: kept for the pairs
        return False
    return all(b[2] <= o[0] or b[0] >= o[2] or b[3] <= o[1] or b[1] >= o[3] for o in occupied)


for r in BIG:
    occupied.append(box(fps[r], 0.3))
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

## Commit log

2026-09-30 Schematic v0.1: JMS583 USB 3.2 Gen 2 to NVMe (M.2 2230)
    Label-style KiCad 9 schematic generated from tools/gen_schematic.py.
    JMS583 pins from datasheet PDS-17001 rev 1.0; USB-C sink with 5.1k CC,
    100 nF on SuperSpeed TX, 220 nF on PCIe TX, 12k REXT, reset RC,
    4.7 uH for the internal 1.0 V buck, TPS82130 3 A buck for the SSD.
    ERC: 0 violations.
    Claude-Session: https://claude.ai/code/session_01RqDGjrUG4GdEsawKGChjmB
    [cartouche-drive.kicad_sch]
2026-09-30 PCB draft v0.1: placement, 4-layer planes, fan-out vias (not for fab)
    30 x 66 mm, 4 layers: In1 solid GND, In2 split VBUS / +3V3 (SSD).
    Parts placed next to the pin they serve; SSD 3.3 V buck under the SSD.
    Freerouting draft: schematic parity 0, 18 unconnected left.
    The 10 Gb/s USB and PCIe pairs must be re-routed as coupled pairs.
    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
    [cartouche-drive.kicad_pcb, cartouche-drive.kicad_sch]
2026-09-30 PCB v0.2 WIP: fix PCIe TX/RX to M.2, new layout, scripted PCIe pairs
    Schematic fix: M.2 PCIe pins are named from the host side (PET = host TX).
    Our TX now goes through the 220 nF caps to PET0/PET1, RX comes from PER0/PER1.
    New 36 x 46 mm layout: JMS583 under the SSD, its PCIe side facing the
    socket's PCIe pins in the same order; USB-C on the left edge.
    The 5 PCIe pairs are routed by the script (straight, one jog, caps staggered),
    1.0 V and REXT pins on that side escape to vias inside the pin ring.
    Still to do: USB 3.2 pairs (B-row vias between the two rows), power pours.
    Not for fabrication yet.
    Claude-Session: https://claude.ai/code/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
    [cartouche-drive.kicad_pcb, cartouche-drive.kicad_sch]
2026-09-30 PCB v0.3 WIP: scripted USB 3.2 pairs, B.Cu power pours, 0201 USB caps
    USB-C B row reached through vias placed between the two pad rows.
    TX1/RX2 straight on F.Cu; TX2/RX1 cross on B.Cu over the In2 ground plane.
    In1 and In2 are both ground; VBUS and +3V3 are pours on B.Cu, split between
    the regulator's VIN and VOUT pads. USB SuperSpeed caps moved to 0201.
    DRC: 0 schematic mismatch, 0 clearance on the pairs, 4 unconnected left.
    Not ready for fabrication.
    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
    [cartouche-drive.kicad_pcb, cartouche-drive.kicad_sch]
2026-09-30 PCB v0.4: fab files, stitching, 1.0 V island, tighter USB pairs
    - USB pairs 0.2/0.1 mm, GND stitching vias, +1V0 island on In2
    - 0 unconnected, 0 parity errors in DRC
    - hardware/fab: Gerbers + drill (zip), JLCPCB BOM and CPL (tools/jlc_files.py)
    - LCSC: C1-C4 C76934, L1 C383386
    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
    [bom-kicad.csv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]
2026-09-30 PCB v0.4 images, board label inside the outline
    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
    [cartouche-drive-B_Cu.gbl, cartouche-drive-B_Mask.gbs, cartouche-drive-B_Paste.gbp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]
2026-09-30 Impedance: 2D field solver, PCIe pairs widened to 0.30 mm
    - tools/impedance.py: finite-difference solver for the JLC04161H-7628 outer layer
    (checks 50 ohm at 0.35 mm single-ended). USB 3.2 0.20/0.10 mm: 86 ohm.
    - tools/widen_pcie.py: PCIe/REFCLK pairs at the 0.5 mm M.2 pitch go from
    0.20 mm (114 ohm) to 0.30 mm wide (89 ohm). DRC: 0 unconnected.
    - Gerbers re-exported.
    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
    [cartouche-drive-B_Cu.gbl, cartouche-drive-B_Mask.gbs, cartouche-drive-B_Paste.gbp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]
2026-09-30 USB-C 3D model on J1, renders with the connector
    The Molex 105450 footprint had no 3D model installed; J1 now uses the LCSC
    model already in hardware/lib (same pad layout, offset 0.355 mm).
    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
    [cartouche-drive.kicad_pcb]
2026-10-01 USB-C face at the board edge (outline moved 0.675 mm)
    The Molex 105450 footprint marks the PCB edge 4.325 mm in front of its origin;
    the board stuck out 0.675 mm in front of the receptacle, so a plug's overmould
    would hit it. tools/usb_edge.py moves the whole outline and the outer pour edges
    right by 0.675 mm (board still 36 x 46 mm); one corner stitching via removed.
    DRC: 0 unconnected. Gerbers, drill, CPL, renders re-exported.
    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
    [cartouche-drive-B_Cu.gbl, cartouche-drive-B_Mask.gbs, cartouche-drive-B_Paste.gbp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]
2026-10-06 BOM with manufacturer part numbers (PCBWay assembly)
    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
    [pcbway-bom.csv]
2026-10-07 AISLER sponsorship: logo placeholder on the bottom silkscreen, Upload to AISLER button, sponsors section
    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
    [cartouche-drive-B_Cu.gbl, cartouche-drive-B_Mask.gbs, cartouche-drive-B_Paste.gbp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]
2026-10-07 README: AISLER logo as PCB sponsor
    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
